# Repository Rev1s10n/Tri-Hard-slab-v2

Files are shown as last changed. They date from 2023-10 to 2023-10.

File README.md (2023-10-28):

# Tri-Hard slab v2
## **English | [繁體中文](README_zh-TW.md)**
Slim all button controller powered by [GP2040-CE](https://gp2040-ce.info/) firmware (v0.7.5), with custom 15 buttons layout mainly for Street Fighter 6 and upcoming games that may support additional keybinding.

Mainly inspired by [Egg On Rice Controller](https://github.com/b1nc/Egg-On-Rice-Controller) by [b1nc](https://github.com/b1nc), [Mille-feuille](https://pomegd.booth.pm/items/2685530) by [ぽめ](https://twitter.com/pomegd) and [BridgeBoard](https://bridgeshop.booth.pm/items/4869470) by [立川 Bridge](https://twitter.com/GBB_tachikawa).

The design is heavily based on [flatbox](https://github.com/jfedor2/flatbox) rev4 by [jfdeor2](https://github.com/jfedor2) and [USB Passthrough Board](https://github.com/OpenStickCommunity/Hardware/tree/main/USB%20Passthrough%20Board) by [TheTrain](https://github.com/TheTrainGoes) and [Lucipher](https://github.com/arntsonl), which is licensed under [CC BY 4.0](https://creativecommons.org/licenses/by/4.0/).

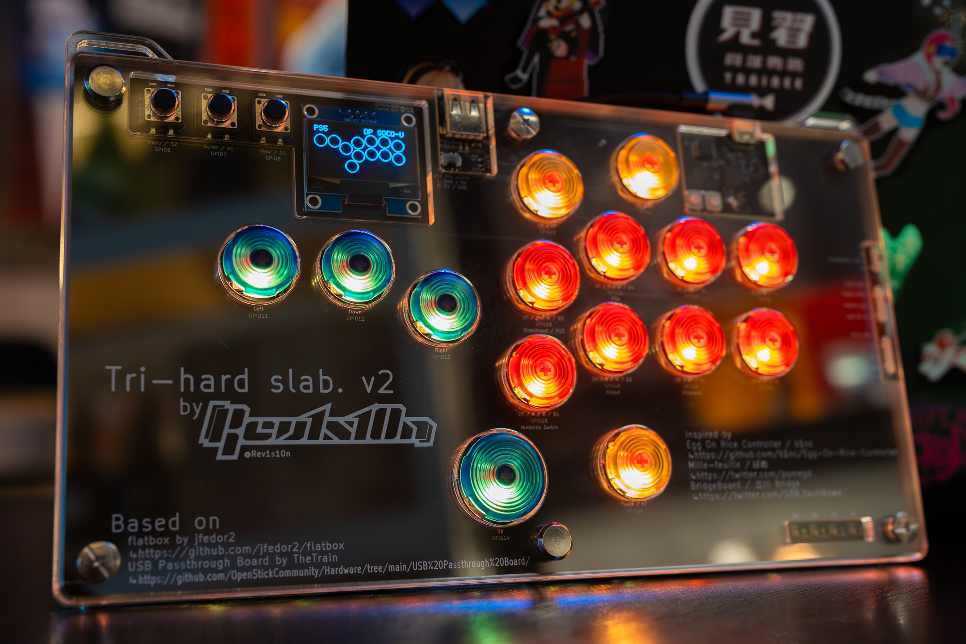
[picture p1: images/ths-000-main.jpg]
The beauty shot

## Key features and specs
- Dimensions: 270x157x15.6mm, with additional foam pad (for better grip on lap) at the bottom added 4mm so the total height is around 20mm.
- Weights: around 800g.
- Laser-cut arcylic sheets for enclosure, with strap holes on the top.
- Main key switches: Kailh low profile Choc v2 red, with hot swap sockets and Punk Workshop's key caps.
- 1 RGB LED for each key, with additional 4 RGB LEDs for player number indication (XInput only).
- USB Type-C connector, and additional USB Type-A for PS passthrough authentication.
- 1.3 inches OLED display for various info.
- 3 slide switches on the right side for focus mode, SOCD mode and LS / RS / DP change in real-time.

Some close up photo for each feature:
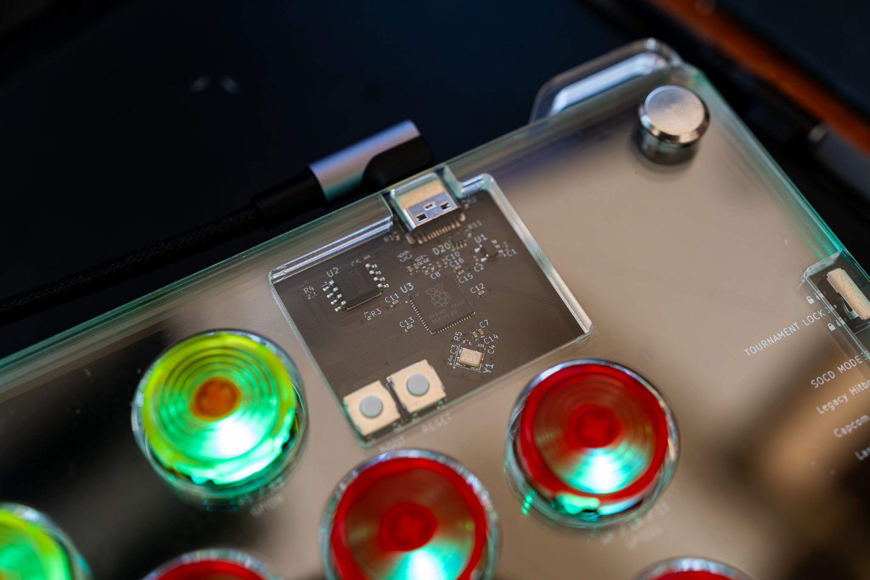
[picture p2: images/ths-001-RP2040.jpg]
The core

_Main circuit is heavily based on flatbox with some components replaced due to parts shortage_
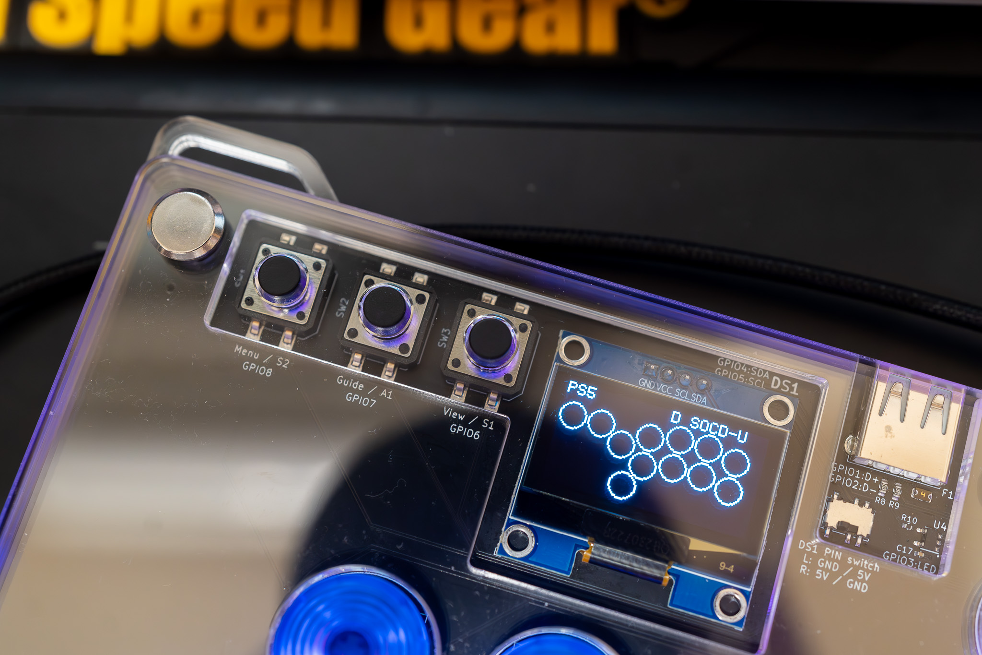
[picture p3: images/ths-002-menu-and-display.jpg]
Functions and display

_3 tactile switches for your daily stuff and the display on the top left, there's additional slide switch for display pin switch (GND / VCC)_
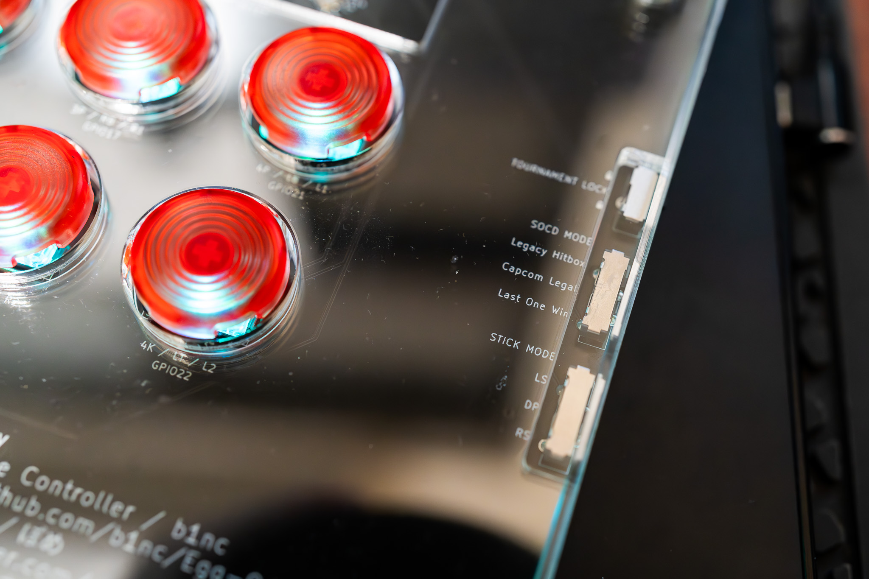
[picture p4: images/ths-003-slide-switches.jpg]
Slide switches

_All slide switches on the right hand side, they sit flush with the enclosure but still can be reach easily_
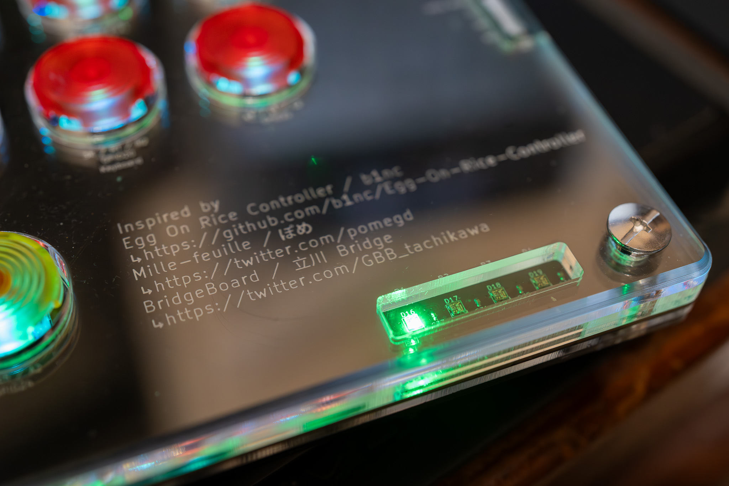
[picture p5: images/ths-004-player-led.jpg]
Player number indication

_It's nice to have but it's only for XInput mode_
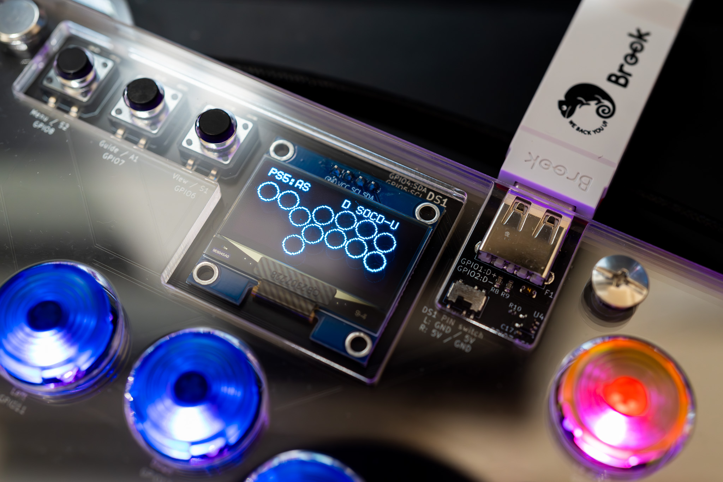
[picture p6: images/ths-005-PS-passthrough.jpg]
Passthrough auth

_PS5 ready, I guess_

## Production files
3D render
_A quick 3D render I did while waiting for acrylic layers_

You can simply download all production files via Hardware files folder, and utilize services like JLCPCB (which is what I did in this case) to order the board. As for the arcrylic layers, use all dxf files and order 1 for each with the exact height mentioned on the filename for optimal result.
To refine it further, send the step files to vendor to ask them to do either fillet (round corner) or chamfer for at least the top layer.

## Source files
The Tri-Hard slab v2 is made with Autodesk Fusion 360 and KiCad 7.0.
Everything is under Source files, include a rough Fusion 360 sketch which is the base of all laser-cut dxf files, step file and for KiCad to align things up. There's additional footprints for some parts that is somewhat interchangeable, but you may need to put extra works like rewire some traces or edit edge cuts.

## Assemble and settings
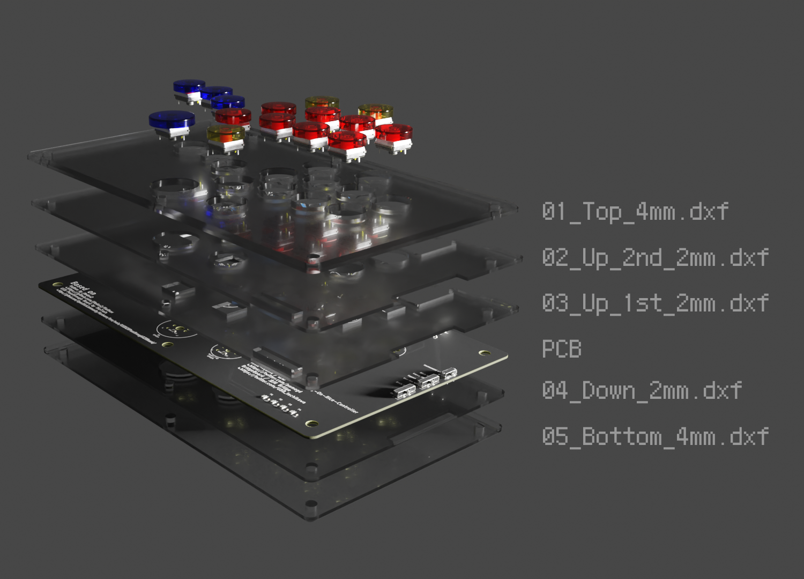
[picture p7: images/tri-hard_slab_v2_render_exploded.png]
Acrylic layers for references

_Layer indication for acrylic_

Besides the PCB and acrylics, you need to order some additional things for the build:
- Kailh low profile switches, obviously, depends on your keycaps, I use v2 specifically as I want to use Punk Workshop's keycap.
- 15 Kailh low profile hotswap socket (for PG1350, which is compatible with PG1353).
- A 1.3 inches OLED display, which you can find pretty much everywhere, usually it's SH1106 driver, make sure to check the pin order and set the pins accordingly with the slide switch next to it.
- 6 M6 sex bolts / Chicago screws with around 14mm length to secure the whole things.

I've compiled a custom firmware with custom button layout for the OLED display and assigned all the GPIO for each keys and switches, which you can find under Firmware and setting files folder, there's a backup setting files as well with some additional RGB LED setting. Here's some GPIO pin mapping info for reference:
|Keys|GPIO|
|-|-|
|Up|14|
|Down|12|
|Left|11|
|Right|13|
|B1/1K/A/Circle|18|
|B2/2K/B/Cross|19|
|B3/1P/X/Square|15|
|B4/2P/Y/Triangle|16|
|L1/4P/LB|21|
|R1/3P/RB|17|
|L2/4K/LT|22|
|R2/3K/RT|20|
|S1/Select/Back|6|
|S2/Start|8|
|L3/LS|10|
|R3/RS|9|
|A1/Home/Guide|7|
|A2/Touch|24|

Additionally here's the GPIO and some other settings for other features and addons:
|Features|GPIO and index|
|-|-|
|RGB LED Data Pin|3|
|Player LEDs|starting from 15 to 18|
|Display SDA|4|
|Display SCL|5|
|Joystick Selection Slider Pin 1|26|
|Joystick Selection Slider Pin 2|25|
|SOCD Cleaning Mode Selection Slider Pin 1|28|
|SOCD Cleaning Mode Selection Slider Pin 2|27|
|PS Passthrough D+|1|
|PS Passthrough D-|2 (automactically selected)|
|Focus Mode Pin|29|

When it's done, to access web configurator again, just hold S2/Start (GPIO8) which is located on the top left and connect to the PC.

## Custom artwork

You can download the PSD file and dxf drawing reference in Custom artwork template folder for top panel.
Print it out and insert the artwork between 01 and 02 acrylic layers.

## Attribution
You're free to use this design as long as you credit to this page.
[Licensed under CC BY 4.0](https://creativecommons.org/licenses/by/4.0/)

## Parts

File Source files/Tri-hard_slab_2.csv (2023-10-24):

Id | Designator | Footprint | Quantity | Designation | Supplier and ref
1 | SW17,SW5,SW15,SW16,SW9,SW13,SW8,SW14,SW11,SW4,SW12,SW7,SW6,SW18,SW10 | SW_Hotswap_Kailh_Choc_V1V2 | 15 | SW_SPST
2 | SW21 | SS-13F24-G050 | 1 | ~
3 | SW3,SW2,SW1 | SW_PUSH-12mm | 3 | SW_Push
4 | SW19,SW20 | SS-12F23-G040 | 2 | ~
5 | UFB | Brook_Universal_Fighting_Board | 1 | brook_ufb
6 | R2,R1 | R_0805_2012Metric | 2 | 5.1k
7 | USB1 | USB_C_Receptacle_HRO_TYPE-C-31-M-12 | 1 | ~

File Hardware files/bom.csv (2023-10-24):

Designator | Footprint | Quantity | Value | LCSC Part #
C1, C10, C2, C8 | 0402 | 4 | 1u | C52923
C11, C12, C13, C14, C15, C16, C17, C18, C19, C20, C21, C22, C23, C24, C25, C26, C27, C28, C29, C30, C31, C32, C33, C34, C35, C36, C5, C6, C7, C9 | 0402 | 30 | 100n | C1525
C3, C4 | 0402 | 2 | 30p | C159804
D1, D10, D11, D12, D13, D14, D15, D16, D17, D18, D19, D2, D3, D4, D5, D6, D7, D8, D9 | SK6812-EC20 | 19 | SK6812 | C2909058
D20 | SOT-363_SC-70-6 | 1 | ~ | C15879
DS1 | 368030501246 | 1 | ~
F1 | 0805 | 1 | Fuse | C116170
R1, R2 | 0402 | 2 | 5.1k | C25905
R10, R4 | 0402 | 2 | 10k | C25744
R11 | 0402 | 1 | 0 | C17168
R3, R5 | 0402 | 2 | 1k | C11702
R6, R7 | 0402 | 2 | 27 | C138021
R8, R9 | 0603 | 2 | 22 | C23345
SW1 | TS-1003S-09526 | 1 | Menu | C455228
SW10 | SW_Hotswap_Kailh_Choc_V1V2 | 1 | 3P / RB
SW11 | SW_Hotswap_Kailh_Choc_V1V2 | 1 | 4P / LB
SW12 | SW_Hotswap_Kailh_Choc_V1V2 | 1 | 1K / A
SW13 | SW_Hotswap_Kailh_Choc_V1V2 | 1 | 2K / B
SW14 | SW_Hotswap_Kailh_Choc_V1V2 | 1 | 3K / RT
SW15 | SW_Hotswap_Kailh_Choc_V1V2 | 1 | 4K / LT
SW16 | SW_Hotswap_Kailh_Choc_V1V2 | 1 | L3
SW17 | SW_Hotswap_Kailh_Choc_V1V2 | 1 | R3
SW18 | SW_Hotswap_Kailh_Choc_V1V2 | 1 | Touch
SW19, SW20 | SKRAAKE010 | 2 | SW_Push | C115354
SW2 | TS-1003S-09526 | 1 | Guide | C455228
SW21 | K3-1245D-F1 | 1 | SW_SPDT | C145859
SW22, SW23 | K3-1346E-F1 | 2 | SW_SP3T | C502339
SW24 | SSSS820101 | 1 | SW_DPDT | C97434
SW3 | TS-1003S-09526 | 1 | View | C455228
SW4 | SW_Hotswap_Kailh_Choc_V1V2 | 1 | Left
SW5 | SW_Hotswap_Kailh_Choc_V1V2 | 1 | Down
SW6 | SW_Hotswap_Kailh_Choc_V1V2 | 1 | Right
SW7 | SW_Hotswap_Kailh_Choc_V1V2 | 1 | Up
SW8 | SW_Hotswap_Kailh_Choc_V1V2 | 1 | 1P / X
SW9 | SW_Hotswap_Kailh_Choc_V1V2 | 1 | 2P / Y
U1 | SOT-23-5 | 1 | TLV73333PDBV | C134139
U2 | SOIC-8_5.23x5.23mm_P1.27mm | 1 | W25Q128JVS
U3 | RP2040-QFN-56 | 1 | RP2040 | C2040
U4 | SOT-23-5 | 1 | SN74LV1T34DBVR | C100024
USB1 | USB_C_Receptacle_HRO_TYPE-C-31-M-12 | 1 | ~ | C165948
USB2 | U-A-24DD-W-16 | 1 | USB_A | C2689981
Y1 | Crystal_SMD_3225-4Pin_3.2x2.5mm | 1 | Crystal_GND24 | C9002

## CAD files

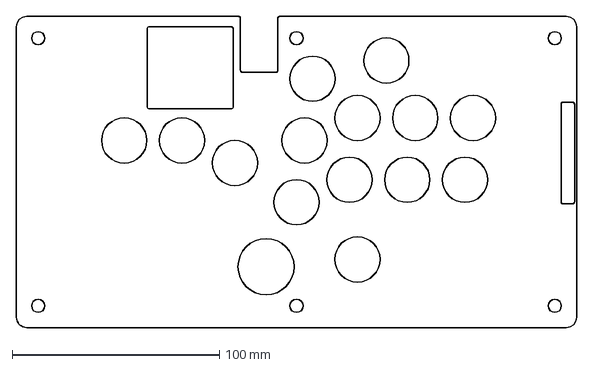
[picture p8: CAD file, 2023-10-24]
Acrylics layers/04_Down_2mm.dxf
270.0 x 150.0 mm

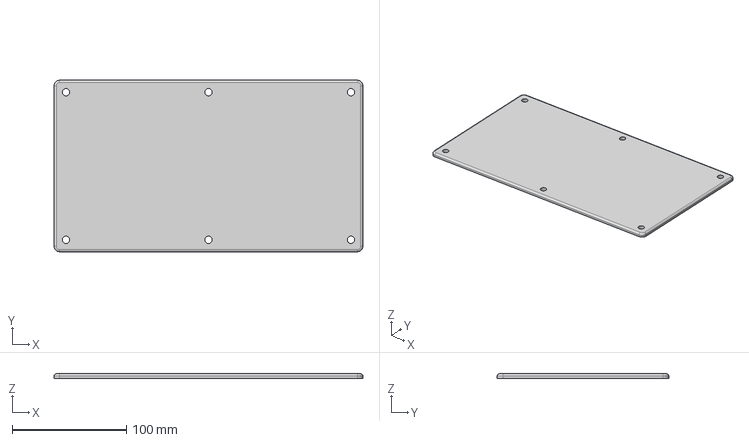
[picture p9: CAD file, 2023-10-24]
Acrylics layers/STEP for additional refinement/05_Bottom_4mm_round.step
270.0 x 150.0 x 4.00 mm

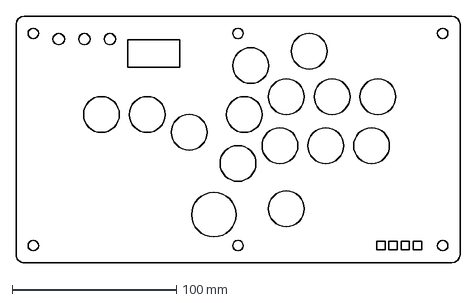
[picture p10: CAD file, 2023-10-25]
Custom artwork template/art_panel_ref.dxf
270.0 x 150.0 mm

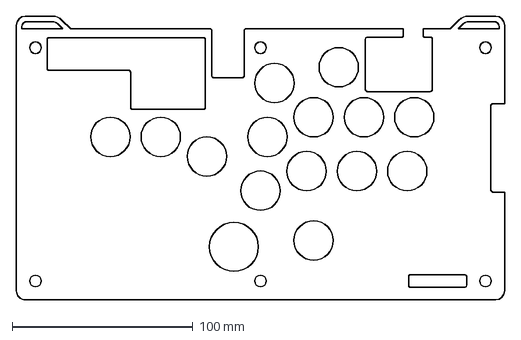
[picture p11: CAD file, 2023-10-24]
Acrylics layers/02_Up_2nd_2mm.dxf
270.0 x 157.0 mm

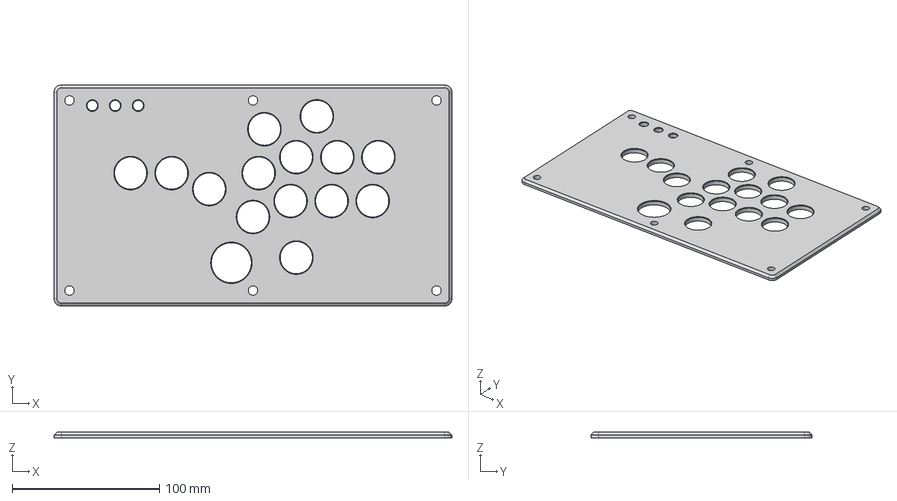
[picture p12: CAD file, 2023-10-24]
Acrylics layers/STEP for additional refinement/01_Top_4mm_chamfer.step
270.0 x 150.0 x 4.00 mm

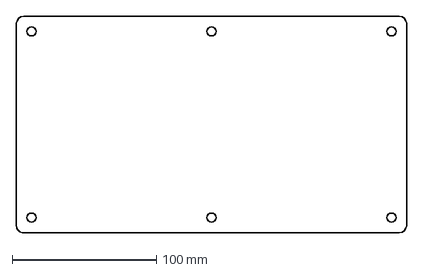
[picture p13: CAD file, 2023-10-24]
Acrylics layers/05_Bottom_4mm.dxf
270.0 x 150.0 mm

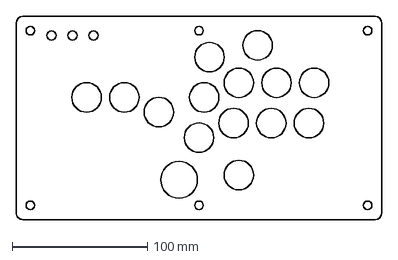
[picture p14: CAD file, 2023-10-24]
Acrylics layers/01_Top_4mm.dxf
270.0 x 150.0 mm

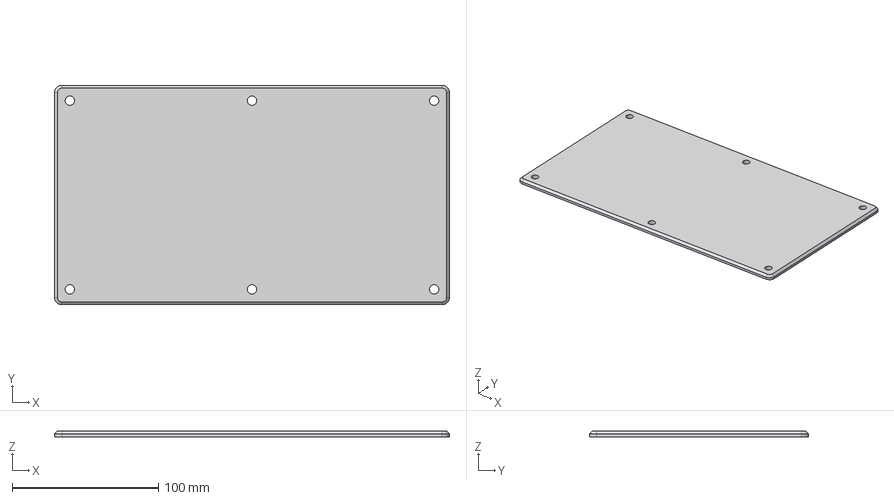
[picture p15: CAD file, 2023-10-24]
Acrylics layers/STEP for additional refinement/05_Bottom_4mm_chamfer.step
270.0 x 150.0 x 4.00 mm

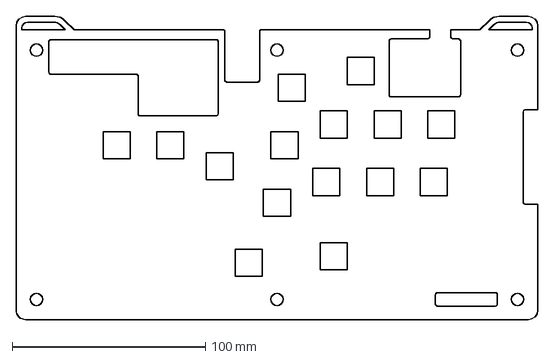
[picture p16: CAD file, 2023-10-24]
Acrylics layers/03_Up_1st_2mm.dxf
270.0 x 157.0 mm

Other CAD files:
Acrylics layers/STEP for additional refinement/01_Top_4mm_round.step
Source files/Raw layout/Panel_v2.f3d

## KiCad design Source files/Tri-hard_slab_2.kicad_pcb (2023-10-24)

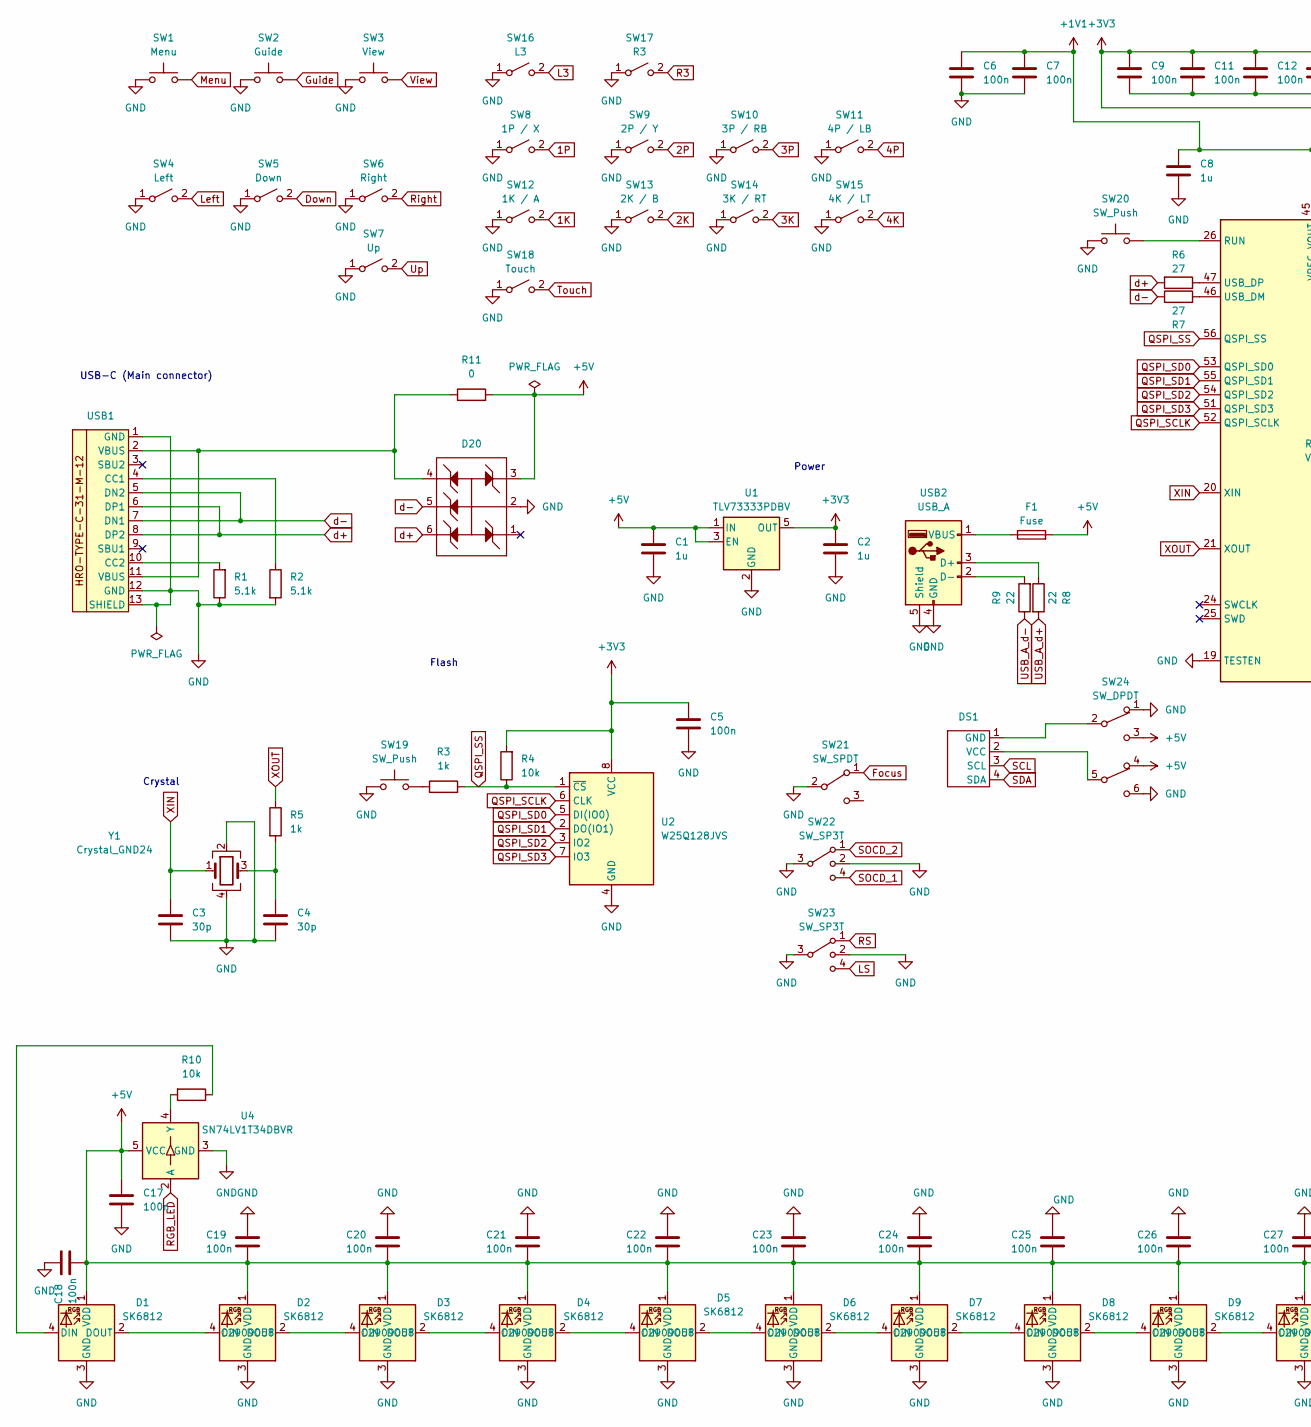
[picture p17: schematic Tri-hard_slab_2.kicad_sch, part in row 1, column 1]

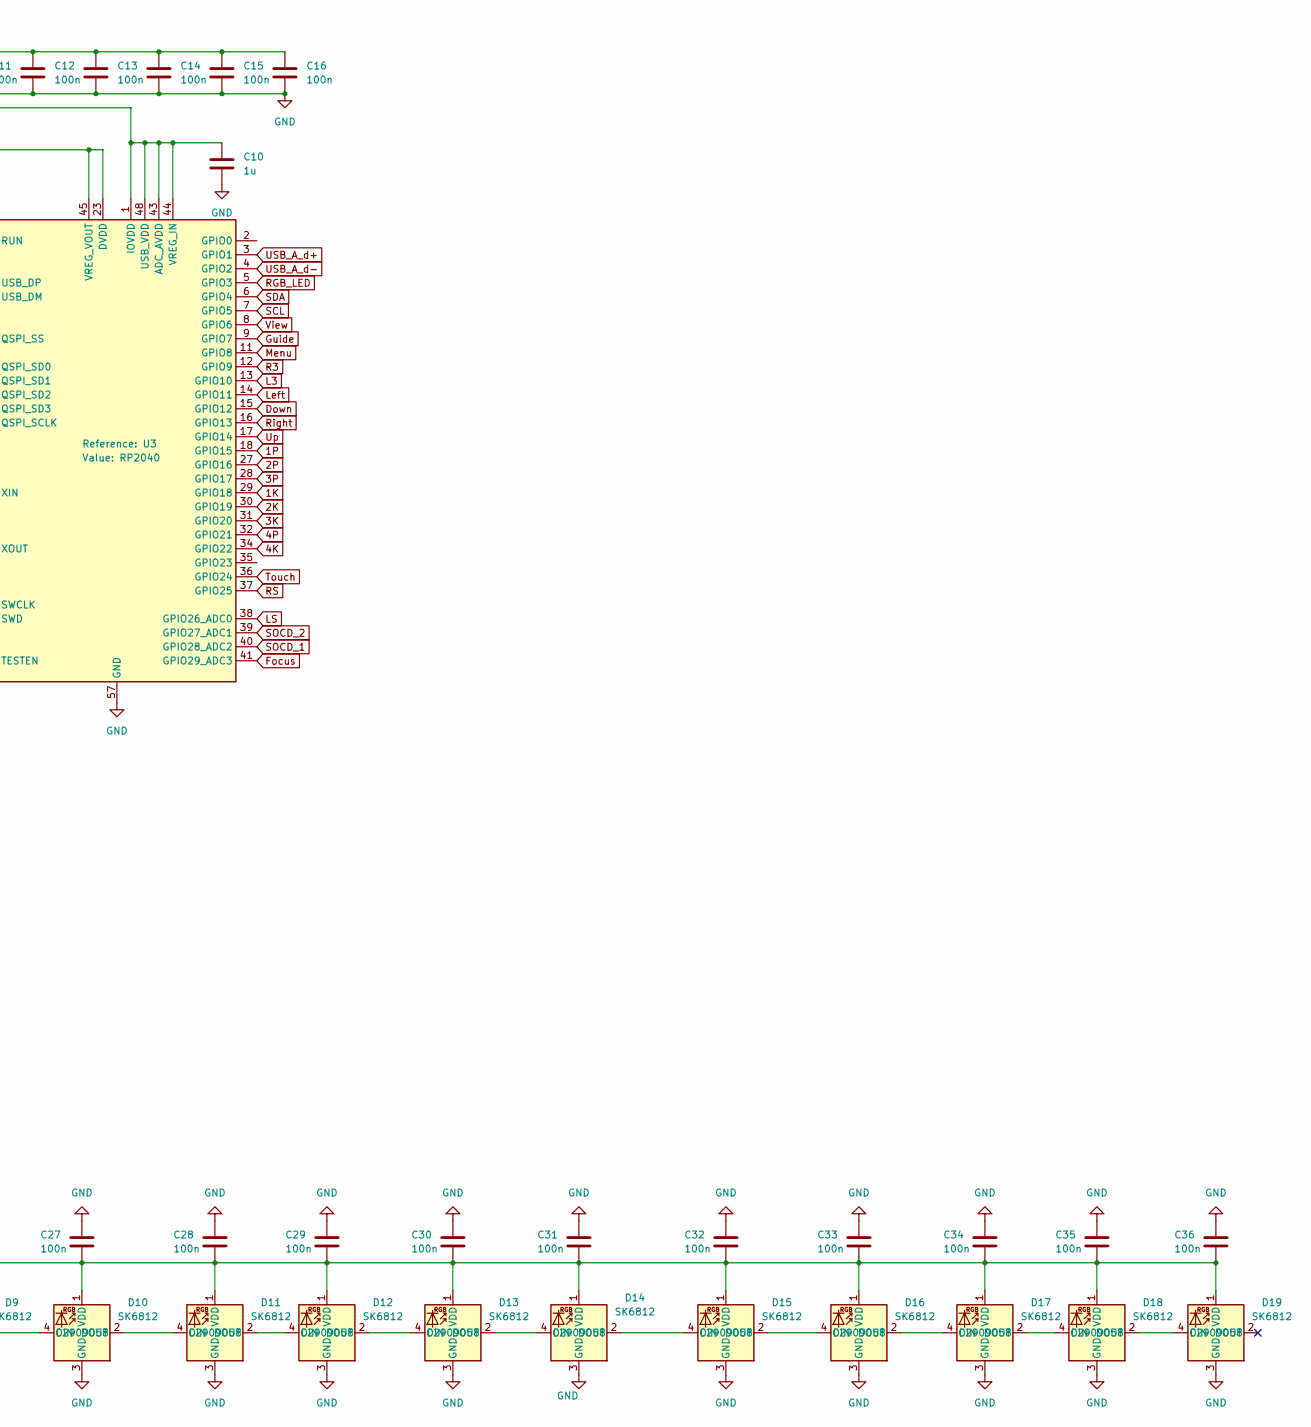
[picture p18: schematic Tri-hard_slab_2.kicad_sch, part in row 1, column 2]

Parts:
C1, C2, C8, C10: 1u; C_0402_1005Metric; LCSC C52923
C3, C4: 30p; C_0402_1005Metric; LCSC C159804
C5, C6, C7, C9, C11, C12, C13, C14, C15, C16, C17, C18, C19, C20, C21, C22, C23, C24, C25, C26, C27, C28, C29, C30, C31, C32, C33, C34, C35, C36: 100n; C_0402_1005Metric; LCSC C1525
D1, D2, D3, D4, D5, D6, D7, D8, D9, D10, D11, D12, D13, D14, D15, D16, D17, D18, D19: SK6812; SK6812-EC20; LCSC C2909058
D20: SOT-363_SC-70-6; LCSC C15879
DS1: 368030501246
F1: Fuse; Fuse_0805_2012Metric; LCSC C116170
R1, R2: 5.1k; R_0402_1005Metric; LCSC C25905
R3, R5: 1k; R_0402_1005Metric; LCSC C11702
R4, R10: 10k; R_0402_1005Metric; LCSC C25744
R6, R7: 27; R_0402_1005Metric; LCSC C138021
R8, R9: 22; R_0603_1608Metric; LCSC C23345
R11: 0; R_0402_1005Metric; LCSC C17168
SW1: Menu; TS-1003S-09526; LCSC C455228
SW2: Guide; TS-1003S-09526; LCSC C455228
SW3: View; TS-1003S-09526; LCSC C455228
SW4: Left; SW_Hotswap_Kailh_Choc_V1V2
SW5: Down; SW_Hotswap_Kailh_Choc_V1V2
SW6: Right; SW_Hotswap_Kailh_Choc_V1V2
SW7: Up; SW_Hotswap_Kailh_Choc_V1V2
SW8: 1P / X; SW_Hotswap_Kailh_Choc_V1V2
SW9: 2P / Y; SW_Hotswap_Kailh_Choc_V1V2
SW10: 3P / RB; SW_Hotswap_Kailh_Choc_V1V2
SW11: 4P / LB; SW_Hotswap_Kailh_Choc_V1V2
SW12: 1K / A; SW_Hotswap_Kailh_Choc_V1V2
SW13: 2K / B; SW_Hotswap_Kailh_Choc_V1V2
SW14: 3K / RT; SW_Hotswap_Kailh_Choc_V1V2
SW15: 4K / LT; SW_Hotswap_Kailh_Choc_V1V2
SW16: L3; SW_Hotswap_Kailh_Choc_V1V2
SW17: R3; SW_Hotswap_Kailh_Choc_V1V2
SW18: Touch; SW_Hotswap_Kailh_Choc_V1V2
SW19, SW20: SW_Push; SKRAAKE010; LCSC C115354
SW21: SW_SPDT; K3-1245D-F1; LCSC C145859
SW22, SW23: SW_SP3T; K3-1346E-F1; LCSC C502339
SW24: SW_DPDT; SSSS820101; LCSC C97434
U1: TLV73333PDBV; SOT-23-5; LCSC C134139
U2: W25Q128JVS; SOIC-8_5.23x5.23mm_P1.27mm
U3: RP2040; RP2040-QFN-56; LCSC C2040
U4: SN74LV1T34DBVR; SOT-23-5; LCSC C100024
USB1: USB_C_Receptacle_HRO_TYPE-C-31-M-12; LCSC C165948
USB2: USB_A; U-A-24DD-W-16; LCSC C2689981
Y1: Crystal_GND24; Crystal_SMD_3225-4Pin_3.2x2.5mm; LCSC C9002

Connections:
1K: SW12.2 (B), U3.29 (GPIO18)
1P: SW8.2 (B), U3.18 (GPIO15)
2K: SW13.2 (B), U3.30 (GPIO19)
2P: SW9.2 (B), U3.27 (GPIO16)
3K: SW14.2 (B), U3.31 (GPIO20)
3P: SW10.2 (B), U3.28 (GPIO17)
4K: SW15.2 (B), U3.34 (GPIO22)
4P: SW11.2 (B), U3.32 (GPIO21)
+1V1: C6.1, C7.1, C8.1, U3.23 (DVDD), U3.45 (VREG_VOUT), U3.50 (DVDD)
+3V3: C2.1, C5.1, C9.1, C10.1, C11.1, C12.1, C13.1, C14.1, C15.1, C16.1, R4.2, U1.5 (OUT), U2.8 (VCC), U3.1 (IOVDD), U3.10 (IOVDD), U3.22 (IOVDD), U3.33 (IOVDD), U3.42 (IOVDD), U3.43 (ADC_AVDD), U3.44 (VREG_IN), U3.48 (USB_VDD), U3.49 (IOVDD)
+5V: C1.1, C17.1, C18.1, C19.1, C20.1, C21.1, C22.1, C23.1, C24.1, C25.1, C26.1, C27.1, C28.1, C29.1, C30.1, C31.1, C32.1, C33.1, C34.1, C35.1, C36.1, D1.1 (VDD), D2.1 (VDD), D3.1 (VDD), D4.1 (VDD), D5.1 (VDD), D6.1 (VDD), D7.1 (VDD), D8.1 (VDD), D9.1 (VDD), D10.1 (VDD), D11.1 (VDD), D12.1 (VDD), D13.1 (VDD), D14.1 (VDD), D15.1 (VDD), D16.1 (VDD), D17.1 (VDD), D18.1 (VDD), D19.1 (VDD), D20.3, F1.2, R11.2, SW24.3 (C), SW24.4 (A), U1.1 (IN), U1.3 (EN), U4.5 (VCC)
Down: SW5.2 (B), U3.15 (GPIO12)
Focus: SW21.1 (A), U3.41 (GPIO29_ADC3)
GND: C1.2, C2.2, C3.2, C4.2, C5.2, C6.2, C7.2, C8.2, C9.2, C10.2, C11.2, C12.2, C13.2, C14.2, C15.2, C16.2, C17.2, C18.2, C19.2, C20.2, C21.2, C22.2, C23.2, C24.2, C25.2, C26.2, C27.2, C28.2, C29.2, C30.2, C31.2, C32.2, C33.2, C34.2, C35.2, C36.2, D1.3 (GND), D2.3 (GND), D3.3 (GND), D4.3 (GND), D5.3 (GND), D6.3 (GND), D7.3 (GND), D8.3 (GND), D9.3 (GND), D10.3 (GND), D11.3 (GND), D12.3 (GND), D13.3 (GND), D14.3 (GND), D15.3 (GND), D16.3 (GND), D17.3 (GND), D18.3 (GND), D19.3 (GND), D20.2, R1.1, R2.2, SW1.1, SW2.1, SW3.1, SW4.1 (A), SW5.1 (A), SW6.1 (A), SW7.1 (A), SW8.1 (A), SW9.1 (A), SW10.1 (A), SW11.1 (A), SW12.1 (A), SW13.1 (A), SW14.1 (A), SW15.1 (A), SW16.1 (A), SW17.1 (A), SW18.1 (A), SW19.1, SW20.1, SW21.2 (B), SW22.2, SW22.3, SW23.2, SW23.3, SW24.1 (A), SW24.6 (C), U1.2 (GND), U2.4 (GND), U3.19 (TESTEN), U3.57 (GND), U4.3 (GND), USB1.1 (GND), USB1.12 (GND), USB1.13 (SHIELD), USB2.4 (GND), USB2.5 (Shield), Y1.2, Y1.4
Guide: SW2.2, U3.9 (GPIO7)
L3: SW16.2 (B), U3.13 (GPIO10)
LS: SW23.4, U3.38 (GPIO26_ADC0)
Left: SW4.2 (B), U3.14 (GPIO11)
Menu: SW1.2, U3.11 (GPIO8)
unnamed: C4.1, R5.2, Y1.3
unnamed: D1.4 (DIN), R10.1
unnamed: D1.2 (DOUT), D2.4 (DIN)
unnamed: D2.2 (DOUT), D3.4 (DIN)
unnamed: D3.2 (DOUT), D4.4 (DIN)
unnamed: D4.2 (DOUT), D5.4 (DIN)
unnamed: D5.2 (DOUT), D6.4 (DIN)
unnamed: D6.2 (DOUT), D7.4 (DIN)
unnamed: D7.2 (DOUT), D8.4 (DIN)
unnamed: D8.2 (DOUT), D9.4 (DIN)
unnamed: D9.2 (DOUT), D10.4 (DIN)
unnamed: D10.2 (DOUT), D11.4 (DIN)
unnamed: D11.2 (DOUT), D12.4 (DIN)
unnamed: D12.2 (DOUT), D13.4 (DIN)
unnamed: D13.2 (DOUT), D14.4 (DIN)
unnamed: D14.2 (DOUT), D15.4 (DIN)
unnamed: D15.2 (DOUT), D16.4 (DIN)
unnamed: D16.2 (DOUT), D17.4 (DIN)
unnamed: D17.2 (DOUT), D18.4 (DIN)
unnamed: D18.2 (DOUT), D19.4 (DIN)
unnamed: D20.4, R11.1, USB1.2 (VBUS), USB1.11 (VBUS)
unnamed: DS1.1 (GND), SW24.2 (B)
unnamed: DS1.2 (VCC), SW24.5 (B)
unnamed: R3.1, SW19.2
unnamed: SW20.2, U3.26 (RUN)
unnamed: R7.2, U3.46 (USB_DM)
unnamed: R6.1, U3.47 (USB_DP)
unnamed: R10.2, U4.4 (Y)
unnamed: R2.1, USB1.4 (CC1)
unnamed: R1.2, USB1.10 (CC2)
unnamed: R8.1, USB2.3 (D+)
unnamed: R9.2, USB2.2 (D-)
unnamed: F1.1, USB2.1 (VBUS)
QSPI_SCLK: U2.6 (CLK), U3.52 (QSPI_SCLK)
QSPI_SD0: U2.5 (DI(IO0)), U3.53 (QSPI_SD0)
QSPI_SD1: U2.2 (DO(IO1)), U3.55 (QSPI_SD1)
QSPI_SD2: U2.3 (IO2), U3.54 (QSPI_SD2)
QSPI_SD3: U2.7 (IO3), U3.51 (QSPI_SD3)
QSPI_SS: R3.2, R4.1, U2.1 (~CS), U3.56 (QSPI_SS)
R3: SW17.2 (B), U3.12 (GPIO9)
RGB_LED: U3.5 (GPIO3), U4.2 (A)
RS: SW23.1, U3.37 (GPIO25)
Right: SW6.2 (B), U3.16 (GPIO13)
SCL: DS1.3 (SCL), U3.7 (GPIO5)
SDA: DS1.4 (SDA), U3.6 (GPIO4)
SOCD_1: SW22.4, U3.40 (GPIO28_ADC2)
SOCD_2: SW22.1, U3.39 (GPIO27_ADC1)
Touch: SW18.2 (B), U3.36 (GPIO24)
USB_A_d+: R8.2, U3.3 (GPIO1)
USB_A_d-: R9.1, U3.4 (GPIO2)
Up: SW7.2 (B), U3.17 (GPIO14)
View: SW3.2, U3.8 (GPIO6)
XIN: C3.1, U3.20 (XIN), Y1.1
XOUT: R5.1, U3.21 (XOUT)
d+: D20.6, R6.2, USB1.6 (DP1), USB1.8 (DP2)
d-: D20.5, R7.1, USB1.5 (DN2), USB1.7 (DN1)

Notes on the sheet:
Crystal
USB-C (Main connector)
Flash
Power

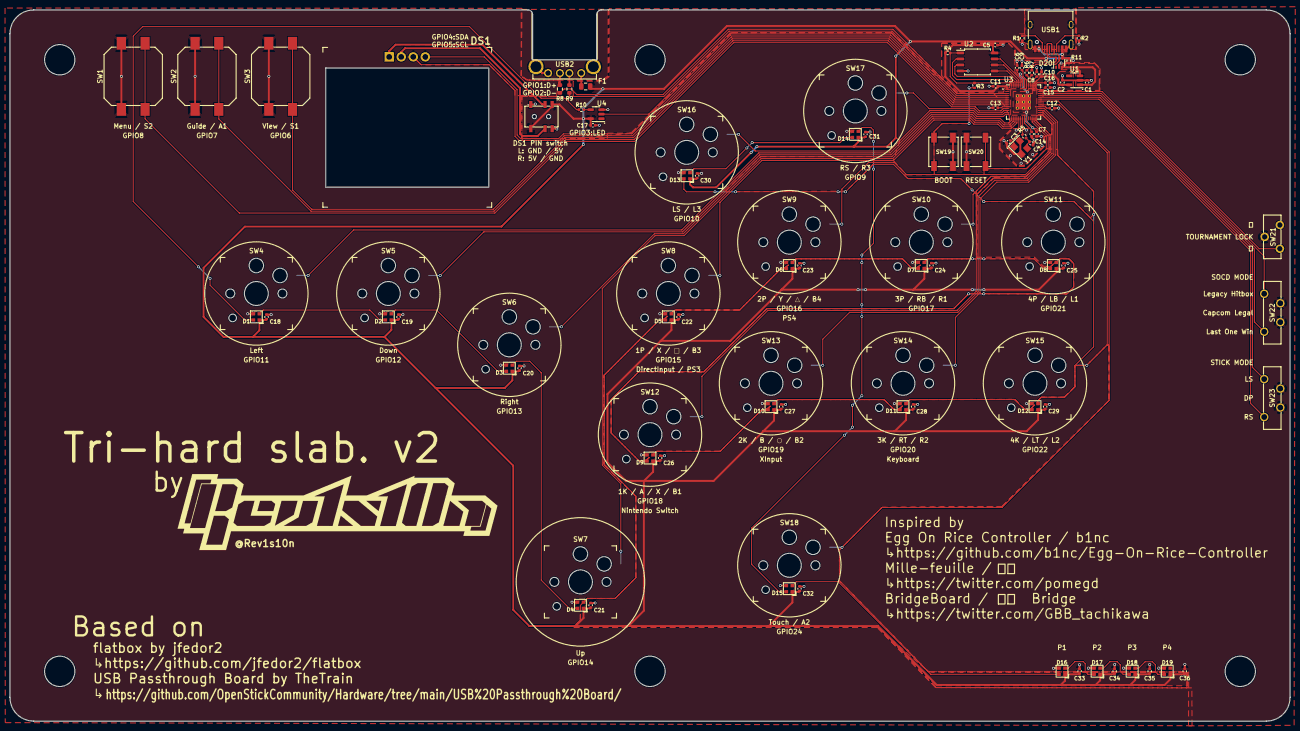
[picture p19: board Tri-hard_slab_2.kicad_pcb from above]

Board: 2 copper layers, 270.0 x 150.0 mm, 106 parts (0 on the bottom side), 75 nets.

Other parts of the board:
M1, M2, M3, M4, M5, M6: MountingHole_6.4mm_M6

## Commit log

2023-10-26 更新關於 Fusion 360 原始檔的說明
2023-10-28 更新關於客製韌體的說明
